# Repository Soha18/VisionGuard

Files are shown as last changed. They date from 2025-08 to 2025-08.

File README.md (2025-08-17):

# VisionGuard 👁️📺

An intelligent IoT child safety system that promotes healthy TV viewing habits by automatically monitoring viewing distance and controlling television access through advanced Time-of-Flight sensing technology.

## 🚀 Features

- **Multi-Zone Distance Monitoring**: VL53L5CX 8×8 zone ToF sensor with 64 independent detection areas
- **Intelligent TV Control**: Configurable IR transmission with LG TV optimization and multi-brand support
- **Dual-Threshold Hysteresis**: Prevents false triggers with smart grace period management
- **Grove Ecosystem Integration**: I2C expansion port supporting 300+ sensor modules (Rev 2)
- **ESPHome Framework**: Web interface with real-time configuration and OTA updates
- **WiFi 6 Ready**: ESP32-C6 with native USB-JTAG and Bluetooth 5.3 LE
- **Professional Grade**: Dual power input, ESD protection, and enhanced reliability

## 🛠️ Hardware Specifications

### Core Components
- **MCU**: ESP32-C6-MINI-1-N4 (RISC-V dual-core, 4MB flash)
- **Sensor**: VL53L5CX Time-of-Flight (50mm-4000mm range, 45°×45° FOV)
- **Power**: USB-C 5V with ST1L05APU33R 3.3V LDO (1.5A capacity)
- **IR**: 940nm LED with 100mA drive capability, 3m+ range
- **Expansion**: Grove I2C connector (Rev 2) with 5V/3.3V power delivery
- **Protection**: Comprehensive ESD, surge, and overcurrent protection

### Performance
- **Detection Range**: 0.3m - 4.0m with ±30mm accuracy
- **Response Time**: <300ms from detection to IR output
- **Update Rate**: 1-60Hz configurable, 5Hz default
- **Power Consumption**: 65-85mA normal, 180-200mA peak
- **Operating Temp**: -10°C to +60°C

## 🔧 Quick Start

### Hardware Setup
1. **Programming**: Connect USB-C cable for native JTAG programming
2. **Installation**: Mount device near TV with clear sensor view of seating area
3. **Power**: Use included USB-C cable or Grove power input (Rev 2)

### Firmware Development
For detailed firmware setup and development environment:
- **ESPHome Environment**: See [FIRMWARE/ESPHome/README.md](FIRMWARE/ESPHome/README.md)
- **Docker Setup**: Complete containerized development environment
- **Configuration Guide**: [FIRMWARE/ESPHome/User_Guide_Rev_1.md](FIRMWARE/ESPHome/User_Guide_Rev_1.md)

### End User Setup
For complete installation and usage instructions:
- **User Manual**: [docs/USER_MANUAL.md](DOCS/visionguard_user_manual.md)
- **Web Interface**: Access device IP after WiFi configuration
- **Troubleshooting**: Common issues and solutions included in user manual

## 🔬 Technical Overview

### Unique Architecture Features
- **STM API Integration**: Custom ESPHome component wrapping STMicroelectronics VL53L3CX/VL53L5CX drivers
- **Dual-Threshold Hysteresis**: Intelligent state management prevents false triggers
- **Multi-Target Processing**: Advanced histogram analysis and spatial filtering
- **Hardware Interrupt Integration**: Low-latency sensor response with ESPHome framework

### Development Stack
- **Framework**: ESPHome with ESP-IDF backend
- **Programming**: Native USB-JTAG via ESP32-C6
- **API**: Custom sensor components and IR protocol libraries
- **Power Management**: Intelligent dual-input switching (Rev 2)

**For complete technical specifications**: See [Technical Documentation](DOCS/technical_doc_rev2.md)

## 🏗️ Hardware Revisions

### Revision 1
- Single-zone VL53L3CX sensor
- USB-C power and programming
- Compact 1.5×5cm form factor
- Production ready design

### Revision 2
- Multi-zone VL53L5CX sensor (8×8 array)
- Grove I2C expansion connector
- Enhanced power management
- Extended environmental specifications

## 📊 Applications

- **Child Safety**: Primary use case for healthy viewing habits
- **Robotics**: Navigation and obstacle avoidance systems  
- **Industrial**: Safety curtains and access control
- **IoT/Smart Home**: Occupancy detection and automation
- **Security**: Spatial intrusion detection systems

### Getting Started
- **Development Environment**: [FIRMWARE/ESPHome/README.md](FIRMWARE/ESPHome/README.md)
- **Technical Architecture**: [docs/TECHNICAL.md](DOCS/technical_doc_rev2.md)
- **Hardware Design**: See [hardware/](hardware/) directory

## 📄 License

This project is licensed under the MIT License - see the [LICENSE](LICENSE) file for details.

---
**Version**: 2.0 | **Hardware**: Rev 1 Production, Rev 2 Development | **Status**: Active Development | **Updated**: August 2025

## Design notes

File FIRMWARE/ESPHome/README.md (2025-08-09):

# ESPHome Firmware Environment for VisionGuard

This directory contains the ESPHome firmware environment for the VisionGuard project. It provides a Docker-based setup for building, flashing, and managing ESPHome devices, including the VisionGuard Rev.1 hardware.

## Requirements

- **Docker**: Ensure Docker is installed on your system. [Install Docker](https://docs.docker.com/get-docker/)
- **Docker Compose**: Required to orchestrate the ESPHome container. [Install Docker Compose](https://docs.docker.com/compose/install/)
- **Supported OS**: Linux (recommended), macOS, or Windows with Docker support.
- **ESP32 Device**: The stack is configured for ESP32-C6-DevKitM-1 hardware.

## Directory Structure

- `docker-compose.yaml` — Docker Compose file to launch the ESPHome service.
- `config/` — Contains all ESPHome YAML configuration files, secrets, and custom components:
  - `vision-guard-rev-1.yml` — Main ESPHome config for VisionGuard Rev.1.
  - `secrets.yaml` — WiFi and sensitive credentials (not included in version control).
  - `my_components/` — Custom ESPHome components (e.g., VL53L3CX sensor driver).

## Getting Started

1. **Clone the Repository**

   ```bash
   git clone <this-repo-url>
   cd FIRMWARE/ESPHome
   ```

2. **Configure Secrets**

   - Copy `config/secrets.yaml.example` to `config/secrets.yaml` (if provided), and fill in your WiFi credentials and other secrets.

3. **Connect Your ESP32 Device**

   - Plug your ESP32 device into your computer. The container is pre-configured to access `/dev/ttyACM0` through `/dev/ttyACM6`.

4. **Start ESPHome**

   Launch the ESPHome dashboard using Docker Compose:

   ```bash
   docker compose up -d
   ```

   This will start the ESPHome web dashboard on port 6052 (default ESPHome port) or as configured.

5. **Access the ESPHome Dashboard**

   Open your browser and go to:

   ```
   http://localhost:6052
   ```
   (Or the port mapped by Docker, if different.)

6. **Build, Upload, and Monitor Firmware**

   - Use the ESPHome dashboard to build and upload firmware to your device.
   - The `config/vision-guard-rev-1.yml` file contains the main configuration for the VisionGuard Rev.1 device, including sensor, IR, and automation logic.

## Notes

- The container runs with `privileged: true` and `network_mode: host` to allow direct access to USB devices and network discovery.
- The `config/` folder is mounted into the container, so any changes to YAML files or custom components are immediately available in ESPHome.
- For advanced configuration, refer to the [ESPHome documentation](https://esphome.io/).

## Stopping the Stack

To stop the ESPHome service:

```bash
docker compose down
```

---

For more details on the VisionGuard firmware logic, see `config/vision-guard-rev-1.yml` and the technical documentation in the main project `DOCS/` folder.

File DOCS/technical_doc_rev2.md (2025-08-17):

# VisionGuard Technical Documentation - Revision 2

## 1. Project Overview

### 1.1 System Description
VisionGuard Revision 2 represents a significant evolution of the intelligent child safety monitoring platform, incorporating advanced multi-zone Time-of-Flight sensing technology and expandable I/O capabilities. The system maintains its core functionality of automatic television access control while adding enhanced detection precision and modular expansion capabilities for diverse applications.

### 1.2 Design Objectives
- **Enhanced Sensing Platform**: Integration of VL53L5CX multi-zone ToF sensor for superior spatial awareness
- **Modular Expansion**: Grove I2C connector enabling integration with external sensors and actuators
- **Robust Power Management**: Dual power input system with intelligent switching and protection
- **Advanced Framework Integration**: Continued development of STMicroelectronics API adaptation with ESPHome
- **Multi-Application Platform**: Optimized for child safety, robotics navigation, industrial automation, and IoT applications
- **Professional Grade**: Enhanced reliability and diagnostic capabilities for commercial deployment

### 1.3 Key Improvements over Revision 1
- **Sensor Upgrade**: VL53L3CX → VL53L5CX (single zone → 8×8 multi-zone detection)
- **Expandability**: Addition of Grove I2C connector for modular sensor integration
- **Power Management**: Intelligent dual-input power switching with surge protection
- **Enhanced Protection**: Comprehensive ESD and overcurrent protection circuits
- **Diagnostic Features**: Hardware status indicators and advanced fault detection

## 2. System Architecture

### 2.1 Core Components Evolution

**Main Control Unit (MCU)**: ESP32-C6-MINI-1-N4 (U1) - Unchanged
- **RISC-V Architecture**: Proven 32-bit dual-core processor
- **Integrated Connectivity**: Native WiFi 6 and Bluetooth 5.3 LE
- **JTAG Programming**: Native USB-JTAG interface with precision USB design
- **Memory**: 4MB embedded flash with expanded configuration storage requirements
- **GPIO Allocation**: Optimized pin assignment for enhanced I/O requirements

**Advanced Distance Sensing System**: VL53L5CXV0GC/1 (U3) - Major Upgrade
- **Multi-Zone Detection**: 8×8 zone array (64 independent measurements) vs. single zone
- **Enhanced Field of View**: 45° × 45° with spatial resolution capabilities
- **Measurement Range**: 50mm to 4000mm with per-zone accuracy
- **Advanced Features**: Gesture recognition, motion detection, multiple target tracking
- **STM API Integration**: Extended driver supporting full multi-zone capabilities
- **Interrupt System**: Hardware interrupt with zone-specific event generation
- **Power Efficiency**: Programmable zone activation for optimized power consumption

**Intelligent Power Architecture**: Dual-Input System
- **Primary Path**: USB-C with standard 5V delivery
- **Auxiliary Path**: Grove connector enabling system-level power integration
- **Automatic Switching**: TPS2121RUXR (U5) seamless transition between sources
- **Protection Stack**: MAX40200AUK+T (U6) + IP4220CZ6,125 (D5) comprehensive fault protection

**Modular Expansion Interface**: Grove I2C Ecosystem (CN1)
- **Standard Compliance**: Seeed Grove 4-pin connector with I2C protocol
- **Power Delivery**: 5V/1A + 3.3V/500mA for diverse sensor requirements
- **Signal Integrity**: Dedicated I2C bus with proper termination and ESD protection
- **Ecosystem Access**: 300+ Grove modules including sensors, actuators, displays, communication

### 2.2 Design Philosophy and Implementation Strategy

**Spatial Intelligence Implementation**:
The transition to multi-zone sensing required fundamental firmware architecture changes:
- **Memory Architecture**: Efficient handling of 64 simultaneous distance measurements
- **Processing Pipeline**: Real-time spatial analysis with sub-100ms response time
- **Algorithm Development**: Custom zone filtering, object classification, and gesture recognition
- **API Integration**: Extended STM VL53L5CX API adaptation maintaining ESPHome compatibility

**Modular Expansion Strategy**:
Grove integration enables transformation from fixed-function device to adaptable platform:
- **Hardware Abstraction**: Standardized I2C interface supporting diverse modules
- **Software Framework**: Dynamic device discovery and configuration management
- **Power Management**: Intelligent power budgeting for multiple concurrent modules
- **Ecosystem Leverage**: Access to established Grove sensor and actuator library

**Reliability Engineering**:
Enhanced protection and fault tolerance for professional applications:
- **Multi-Stage Protection**: ESD, overcurrent, and surge protection on all external interfaces
- **Fault Detection**: Real-time monitoring with diagnostic reporting capabilities
- **Graceful Degradation**: System maintains core functionality during component failures
- **Power Redundancy**: Automatic failover between power sources without interruption

### 2.3 Hardware Interface Specifications

**VL53L5CX Control Interface**:
- **I2C Address**: 0x29 (7-bit addressing)
- **Control Signals**: 
  - LPN (Low Power): GPIO-controlled power management
  - INT: Interrupt output for measurement completion
  - RST: Hardware reset capability
- **Supply Requirements**: 2.8V I/O, 1.8V analog (internally regulated)
- **Signal Processing**: On-chip histogram analysis and multi-target separation

**Grove Connector Pinout** (CN1):
```
Pin 1: VCC (5V, 1A max, fused)
Pin 2: GND (common ground)
Pin 3: I2C_SDA_EXT (3.3V logic, 2.2kΩ pull-up)
Pin 4: I2C_SCL_EXT (3.3V logic, 2.2kΩ pull-up)
```

**Power Input Specifications**:
- **USB-C**: 5V ±5%, 1.5A maximum with PD negotiation
- **Grove**: 5V ±10%, 1A maximum auxiliary input
- **Switching**: <10ms transition time between sources
- **Efficiency**: >90% power conversion efficiency

## 3. Firmware Architecture and Multi-Zone Integration

**Enhanced Software Framework**: ESPHome with expanded VL53L5CX integration
**Multi-Zone Processing**: Advanced spatial algorithms for 64-zone analysis
**Grove Module Support**: Dynamic I2C device discovery and configuration

### 3.1 VL53L5CX Multi-Zone Implementation

**Unique STM API Integration Enhancement**:
- **64-Zone Data Handling**: Real-time processing of 8×8 distance matrix
- **Spatial Algorithms**: Custom zone filtering and object recognition
- **Memory Optimization**: Efficient handling of multi-zone data structures
- **Interrupt Processing**: Zone-specific event handling and prioritization
- **Configuration Management**: Per-zone parameter adjustment capabilities

**Multi-Zone Configuration Parameters**:
```yaml
VL53L5CX Advanced Settings:
- Resolution Mode: 8×8 (64 zones) or 4×4 (16 zones) selectable
- Detection Range: 50mm to 4000mm per zone
- Update Rate: 1-60Hz with zone-dependent timing
- Target Order: Distance or signal strength prioritization
- Zone Filtering: Configurable ignore masks for specific areas
- Gesture Detection: Motion pattern recognition algorithms
```

### 3.2 Enhanced Control Logic

**Multi-Zone State Machine**:
1. **SPATIAL_MONITORING**: Continuous 64-zone distance measurement
2. **ZONE_ANALYSIS**: Object detection and classification per zone  
3. **GESTURE_RECOGNITION**: Movement pattern analysis
4. **MULTI_TARGET_TRACKING**: Simultaneous object tracking
5. **INTELLIGENT_ACTION**: Context-aware response execution

**Advanced Threshold Management**:
- **Zone-Specific Thresholds**: Individual distance limits per detection zone
- **Spatial Hysteresis**: 2D hysteresis preventing edge oscillations  
- **Gesture Triggers**: Hand wave detection for user interaction
- **Multi-Object Logic**: Handling multiple simultaneous detections
- **Adaptive Sensitivity**: Learning algorithms for environment adaptation

**Grove Module Integration**:
- **Device Auto-Discovery**: I2C scanning and device identification
- **Dynamic Configuration**: Runtime module parameter adjustment
- **Data Fusion**: Combining VL53L5CX data with external sensor inputs
- **Modular Actions**: Triggering external devices via Grove modules

### 3.3 IR Protocol and External Control

**Enhanced IR Protocol Support**:
- **Multi-Device Control**: Simultaneous control of multiple IR devices
- **Zone-Based Actions**: Different actions for different spatial zones
- **Grove IR Modules**: Support for external IR transmitters via Grove
- **Protocol Library**: Expanded support for TV, projector, and AV equipment

## 4. Hardware Design Specifications - Revision 2

### 4.1 Advanced Electrical Design

**Power Consumption Analysis** (Multi-Zone Operation):
| Operating Mode | Current (mA) | Power (mW) | Notes |
|---|---|---|---|
| 64-Zone Active Sensing | 95-120 | 315-400 | VL53L5CX active |
| 16-Zone Reduced Power | 70-85 | 230-280 | 4×4 mode |
| WiFi + Multi-Zone | 150-180 | 500-600 | Peak operation |
| Grove Module Active | +20-50 | +65-165 | Variable per module |
| Deep Sleep | 0.08-0.15 | 0.25-0.5 | Enhanced sleep mode |

**Power Distribution Design**:
- **5V Rail**: Dual-input with TPS2121 automatic switching
- **3.3V Main**: ST1L05APU33R providing 1.5A capability
- **Current Budget**: MCU (80mA) + VL53L5CX (40mA) + Grove (50mA) = 170mA typical
- **Surge Protection**: MAX40200 provides 4A peak current limiting
- **ESD Protection**: IP4220CZ6,125 on all external interfaces

**Signal Integrity Enhancements**:
- **Multi-Zone Data**: High-speed I2C with 64-zone data bandwidth
- **USB Differential Pairs**: Maintained 90Ω ±10% impedance
- **Grove I2C**: Dedicated 33Ω series termination for signal integrity
- **Power Distribution**: Enhanced decoupling with zone-specific filtering
- **Ground Plane**: Improved ground distribution for multi-zone sensor

### 4.2 PCB Layout Evolution

**Enhanced Form Factor Considerations**:
- **Sensor Positioning**: VL53L5CX optimally placed for maximum FOV
- **Grove Connector**: Side-mounted for easy external module connection
- **USB-C Orientation**: Maintained back-side positioning for clean installation
- **Component Density**: Increased component count with optimized placement
- **Thermal Management**: Enhanced thermal design for higher power operation

### 4.3 Bill of Materials - Revision 2 Critical Components

| Designator | Component | Part Number | Function | Rev1 Comparison |
|---|---|---|---|---|
| U1 | ESP32-C6 | ESP32-C6-MINI-1-N4 | Main MCU | Unchanged |
| U3 | Multi-Zone ToF | VL53L5CXV0GC/1 | 64-zone distance sensing | Major upgrade from VL53L3CX |
| U2 | LDO Regulator | ST1L05APU33R | 3.3V regulation | Unchanged |
| U5 | Power Switch | TPS2121RUXR | Dual-input switching | New addition |
| U6 | Current Limiter | MAX40200AUK+T | Overcurrent protection | New addition |
| D5 | ESD Protector | IP4220CZ6,125 | USB/Grove protection | New addition |
| CN1 | Grove Connector | ZX-HY2.0-4PZZ | I2C expansion | New addition |
| Q1 | NPN Transistor | SS8050 | IR LED driver | Unchanged |
| LED1 | IR Emitter | DY-IRS302320C/6.5T | IR transmission | Unchanged |

## 5. Performance Specifications - Revision 2

### 5.1 Multi-Zone Detection Performance
| Parameter | Specification | Improvement over Rev1 |
|---|---|---|
| Detection Zones | 64 (8×8) or 16 (4×4) | +6300% spatial resolution |
| Zone Resolution | 5.6° per zone | Individual zone targeting |
| Simultaneous Targets | Up to 64 | Multiple object tracking |
| Gesture Recognition | Hand/body gestures | New capability |
| Update Rate | 1-60Hz per zone | Maintained with 64× data |
| Spatial Accuracy | ±30mm per zone | Maintained across all zones |

### 5.2 Grove Integration Performance
| Parameter | Specification |
|---|---|
| I2C Bus Speed | Up to 400kHz |
| Module Discovery | <1s auto-detection |
| Concurrent Modules | Up to 8 devices |
| Power Delivery | 5V @ 1A, 3.3V @ 500mA |
| Cable Length | Up to 2m Grove cable |

### 5.3 Enhanced Environmental Specifications
| Parameter | Minimum | Maximum | Unit | Notes |
|---|---|---|---|---|
| Operating Temperature | -20 | +70 | °C | Extended range |
| Multi-Zone Operation | -10 | +60 | °C | Full 64-zone capability |
| Humidity | 5 | 95 | % RH | Non-condensing |
| Vibration Resistance | - | 10G | - | Enhanced for mobile robotics |

## 6. Applications and Use Cases - Revision 2

### 6.1 Enhanced Child Safety Applications
- **Multi-Child Detection**: Simultaneous monitoring of multiple children
- **Spatial Awareness**: Zone-specific safety enforcement  
- **Gesture Control**: Hand wave commands for interaction
- **Parent Override**: Gesture-based temporary disable

### 6.2 Robotics and Automation
- **Navigation**: 64-zone obstacle detection for mobile robots
- **Localization**: Spatial landmark detection and mapping
- **Human-Robot Interaction**: Gesture-based robot control
- **Industrial Automation**: Multi-zone safety curtains and access control

### 6.3 IoT and Smart Home Integration
- **Occupancy Detection**: Room-level presence sensing with zone resolution
- **Activity Recognition**: Movement pattern analysis for smart lighting
- **Security Systems**: Intrusion detection with spatial discrimination
- **Energy Management**: Zone-based HVAC control optimization

### 6.4 Grove Ecosystem Integration
- **Environmental Monitoring**: Temperature, humidity, air quality sensors
- **Display Systems**: OLED/LCD status displays via Grove
- **Wireless Communication**: LoRa, Zigbee modules for extended connectivity
- **Actuator Control**: Servo motors, relays, and output devices

## 7. Manufacturing and Quality - Revision 2

### 7.1 Advanced Assembly Requirements
- **Multi-Zone Calibration**: Factory calibration of 64-zone sensor array
- **Grove Interface Testing**: Automated testing of I2C expansion capability
- **Dual Power Testing**: Verification of automatic power switching functionality
- **Spatial Alignment**: Precise sensor mounting for optimal FOV coverage

### 7.2 Enhanced Quality Assurance
- **Multi-Zone Verification**: Per-zone distance accuracy testing
- **Grove Compatibility**: Testing with standard Grove sensor modules
- **Power Management**: Dual-input switching and protection verification
- **Long-term Reliability**: Extended burn-in testing for commercial applications

---

*Document Version: 2.0*  
*Hardware Revision: 2*  
*Supersedes: VisionGuard Revision 1 Technical Documentation*  
*Last Updated: August 2025*  
*Classification: Advanced Technical Design Specification*

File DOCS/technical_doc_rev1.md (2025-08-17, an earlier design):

# VisionGuard Technical Documentation - Revision 1

## 1. Project Overview

### 1.1 System Description
VisionGuard is an intelligent child safety monitoring system designed to automatically control television access based on viewing distance. The device employs Time-of-Flight (ToF) sensing technology to continuously monitor viewer proximity and executes predefined actions via infrared transmission when unsafe viewing distances are detected.

### 1.2 Design Objectives
- **Primary Function**: Proof of concept for integrating VL53L3CX ToF sensor with ESP32-C6 architecture and implementation of STMicroelectronics API adaptation with ESPHome/ESP-IDF framework
- **Child Safety Application**: Automatic enforcement of safe TV viewing distances as primary use case
- **Versatile Platform**: Expandable architecture for robotics applications (exploration robots, localization systems), gate control systems, and industrial proximity monitoring
- **Smart Integration**: WiFi connectivity and web interface for IoT applications
- **Configurable Response**: User-defined thresholds and behavioral actions

## 2. System Architecture

### 2.1 Core Components Selection Strategy

**Main Control Unit (MCU)**: ESP32-C6-MINI-1-N4 (U2)
- **RISC-V Architecture**: Modern 32-bit processor with dual-core capability
- **Integrated Connectivity**: Native WiFi 6 (802.11ax) and Bluetooth 5.3 LE
- **JTAG Programming**: Native USB-JTAG interface requiring precise USB differential pair design
- **Memory**: 4MB embedded flash for application code and configuration storage

**Distance Sensing System**: VL53L3CXV0DH/1 (U1) - STMicroelectronics Time-of-Flight Sensor
- **Measurement Range**: 50mm to 4000mm operational range covers typical applications
- **Accuracy**: ±3% precision at 1-2m distances (optimal for most use cases)
- **I2C Interface**: Standard communication protocol with configurable address (0x29)
- **STM API Adaptation**: Custom driver integration with ESPHome framework - unique implementation
- **Interrupt Capability**: Hardware interrupt on measurement completion reduces polling overhead

**Power Management Architecture**: ST1L05APU33R (U3) Low-Dropout Regulator
- **Input Range**: 5V USB-C input with comprehensive surge protection
- **Output**: Stable 3.3V supply rated at 1.5A maximum current
- **Voltage Drop Calculation**: 200mV typical dropout ensures 3.1V minimum at 300mA load
- **Current Budget**: MCU (80mA) + Sensor (20mA) + IR LED (100mA peak) = 200mA minimum
- **Thermal Protection**: Integrated over-temperature shutdown with thermal pad
- **Package**: SOT-323 surface mount optimized for 1.5×5cm PCB constraint

**Infrared Transmission System**: DY-IRS302320C/6.5T (U5) with SS8050 Driver (Q1)
- **Wavelength**: 940nm optimized for consumer electronics IR receivers
- **Drive Current Calculation**: 100mA peak through 220Ω base resistor with β=200 transistor gain
- **Power Dissipation**: 330mW peak (100mA × 3.3V) during transmission bursts
- **Protocol Flexibility**: Configurable IR protocols with LG TV as default tested implementation
- **Range**: >3m transmission distance for typical applications

### 2.2 Critical Design Considerations

**USB-C Interface Design**: TYPE-C 16PLT-H10.0 (U4)
The ESP32-C6 uses native USB-JTAG (not UART bridge) requiring precise differential pair design:
- **Impedance Control**: 90Ω ±10% differential impedance maintained across PCB traces
- **Trace Length**: D+/D- matched within ±0.1mm, total length <50mm for signal integrity
- **Capacitive Loading**: 4.7µF bulk capacitors positioned <5mm from connector
- **CC Resistors**: 5.1kΩ precision resistors for USB-C power negotiation
- **Current Limiting**: MF-MSMF110/16-2 resettable fuse rated for inrush protection

**PCB Layout Architecture**: 1.5×5cm Form Factor
- **Orientation Strategy**: USB-C connector on back side, sensor and IR LED on front side
- **Installation Advantage**: Front-facing sensors allow direct TV screen mounting
- **Component Density**: High-density layout with 0402 passive components
- **Ground Plane**: Continuous ground pour with strategic via stitching
- **Power Distribution**: Star topology from LDO to minimize voltage drops
- **Bulk Capacitance**: 22µF tantalum + 4.7µF ceramic near USB connector for inrush current limiting
- **Thermal Management**: Thermal vias under power components for heat dissipation

**I2C Bus Implementation**:
- **Clock Frequency**: 38kHz optimized for VL53L3CX sensor timing requirements
- **Pull-up Resistors**: 2.2kΩ (R4, R5) calculated for 3.3V logic with 400pF bus capacitance
- **GPIO Assignment**: SDA=GPIO6, SCL=GPIO7 with internal weak pull-ups disabled
- **Signal Integrity**: <10pF parasitic capacitance maintained through careful routing

## 3. Firmware Architecture and STM API Integration

**Software Framework**: ESPHome with ESP-IDF backend and custom STM API adaptation
**Real-Time OS**: FreeRTOS kernel for task scheduling
**Development Framework**: YAML configuration with C++ lambda extensions

### 3.1 Unique STM API Adaptation
This project features a novel integration of STMicroelectronics VL53L3CX API with the ESPHome framework:
- **Custom Component**: Native ESPHome component wrapping STM's official API
- **Memory Management**: Adaptation of STM's dynamic allocation to ESP-IDF heap management
- **Interrupt Handling**: Integration of STM interrupt callbacks with ESPHome's GPIO system
- **Configuration Bridge**: YAML parameter mapping to STM's configuration structures
- **Multi-Target Support**: Full exposure of STM's advanced ranging capabilities

### 3.2 Sensor Management System

**VL53L3CX Driver Configuration**:
- Distance Mode: MEDIUM (up to 2.90m range)
- Timing Budget: 80ms (accuracy vs. speed balance)
- Update Interval: 200ms (system responsiveness)
- Signal Processing: Exponential moving average (α=0.1)

**Multi-Target Processing Algorithm**: Custom histogram analysis with STM API integration
- Merge Threshold: 12000 units (target separation)
- Noise Threshold: 50 units (weak signal rejection)
- Signal Rate Limit: 0.1 MCPS (minimum acceptable return)
- Sigma Threshold: 60mm (measurement uncertainty limit)

### 3.3 Control Logic Implementation

**State Machine Architecture**:
1. MONITORING: Continuous distance measurement
2. GRACE_PERIOD: Countdown before action execution  
3. ACTION_ACTIVE: IR command transmission
4. RECOVERY_HOLD: Waiting for distance recovery

**Dual-Threshold Hysteresis System**:
- Close Threshold: 0.8m default (user configurable 0.3-2.0m)
- Far Threshold: 1.0m default (user configurable 0.5-3.0m)
- Dead Band: Prevents oscillation between states
- Grace Period: 2s default delay before action execution

**Action Execution Framework**:
- Near Actions (child too close): Mute, Power Off, Input switching, Navigation commands
- Far Actions (child moved away): Unmute, Power On, Input restoration
- IR repeat count: 3 transmissions with 50ms intervals
- Command verification through state tracking

### 3.4 IR Protocol Implementation

**Configurable Protocol Support**: The system supports multiple IR protocols with LG TV as the default tested configuration:
- **Primary Protocol**: NEC encoding with LG address prefix (0x20DF)
- **Alternative Protocols**: Samsung, Sony, Panasonic (configurable via firmware)
- **Carrier Frequency**: 38kHz with 50% duty cycle
- **Bit Encoding**: PWM with protocol-specific timing requirements

**LG TV Command Set (Default Configuration)**:
```
Verified Commands:
- Power: 0x20DF10EF
- Mute: 0x20DF906F  
- Input: 0x20DFD02F
- HDMI1: 0x20DF738C
- HDMI2: 0x20DF33CC
- HDMI3: 0x20DF9768
```

**Transmission Strategy**:
- Multiple transmission repeats (user configurable 1-5)
- Inter-command delays (50ms) prevent receiver overflow
- Queue management for sequential commands
- Error recovery through state machine reset

## 4. Hardware Design Specifications

### 4.1 Electrical Design and Power Analysis

**Power Consumption Analysis**:
| Operating Mode | Current (mA) | Power (mW) | Duration |
|---|---|---|---|
| Active Sensing | 65-85 | 215-280 | Continuous |
| WiFi Transmission | 120-150 | 400-500 | Burst |
| IR Transmission | 180-200 | 600-660 | 100ms |
| Deep Sleep | 0.05-0.1 | 0.15-0.3 | Standby |

**LDO Design Calculations**:
- Input Voltage: 5.0V (USB-C nominal)
- Output Voltage: 3.3V regulated
- Maximum Load Current: 200mA (continuous), 300mA (peak)
- Voltage Drop: 1.7V (5.0V - 3.3V)
- Power Dissipation: 340mW @ 200mA load
- Thermal Resistance: 120°C/W (SOT-323 package)
- Temperature Rise: 41°C above ambient (acceptable for ≤45°C ambient)

**Signal Integrity Requirements**:
- I2C Bus: ±5% tolerance, <10pF parasitic capacitance
- USB Differential Pairs: 90Ω ±10% impedance, ±0.1mm length matching
- IR Drive Circuit: Fast rise/fall times (<1µs) for 38kHz modulation
- Power Rails: <50mV ripple at full load with bulk capacitor filtering

### 4.3 Bill of Materials - Critical Components

| Designator | Component | Part Number | Function | Selection Criteria |
|---|---|---|---|---|
| U2 | ESP32-C6 | ESP32-C6-MINI-1-N4 | Main MCU | RISC-V architecture, native USB-JTAG, WiFi 6 |
| U1 | ToF Sensor | VL53L3CXV0DH/1 | Distance measurement | 4m range, I2C interface, STM API support |
| U3 | LDO Regulator | ST1L05APU33R | 3.3V regulation | 1.5A rating, low dropout, thermal protection |
| U5 | IR LED | DY-IRS302320C/6.5T | IR transmission | 940nm wavelength, 100mA drive capability |
| Q1 | NPN Transistor | SS8050 | IR LED driver | β=200 gain, fast switching, 100mA collector |
| U4 | USB-C Connector | TYPE-C 16PLT-H10.0 | Power/JTAG interface | USB-C standard, robust mounting |

## 5. Programming and Development Interface

**Firmware Flashing Procedure**:
- **Interface**: USB-C connector with native ESP32-C6 USB-JTAG support
- **Protocol**: JTAG debugging protocol (not UART bridge)
- **Tools**: ESPHome command line, ESP-IDF, or OpenOCD
- **Flash Process**: Direct JTAG programming via USB-C connection
  1. Connect USB-C cable to development host
  2. Auto-detection via USB-JTAG bridge
  3. Execute: `esphome run vision-guard-rev-1.yml`
  4. Monitor via serial console or JTAG debugger

## 6. Performance Specifications

### 6.1 Detection Performance
| Parameter | Specification | Test Condition |
|---|---|---|
| Detection Range | 0.3m - 4.0m | Standard reflective target |
| Accuracy | ±30mm | At 1m distance |
| Response Time | <300ms | From detection to IR output |
| False Positive Rate | <1% | 8-hour continuous operation |
| Update Rate | 5 Hz | Configurable 1-60 Hz |

### 6.2 Environmental Specifications
| Parameter | Minimum | Maximum | Unit |
|---|---|---|---|
| Operating Temperature | -10 | +60 | °C |
| Storage Temperature | -40 | +85 | °C |
| Relative Humidity | 10 | 90 | % RH |
| Altitude | 0 | 3000 | meters |

### 6.3 Network Performance
| Parameter | Specification |
|---|---|
| WiFi Standards | 802.11 b/g/n/ax (2.4GHz) |
| Security | WPA3-Personal, WPA2-Personal |
| Range | 30m typical indoor |
| Connection Time | <10s from power-on |
| OTA Update Size | <2MB typical |

## 7. Safety and Compliance

### 7.1 Electrical Safety
- **Input Protection**: TVS diode for surge protection
- **Current Limiting**: Resettable fuse prevents overcurrent
- **Isolation**: No galvanic connection between USB and IR circuits
- **EMC**: Design practices for FCC Part 15 Class B compliance

### 7.2 IR Safety
- **Eye Safety**: IR LED power limited to IEC 62471 Class 1
- **Exposure Duration**: Pulse-based transmission minimizes continuous exposure
- **Wavelength**: 940nm outside visible spectrum

---

*Document Version: 1.0*  
*Hardware Revision: 1*  
*Firmware Version: ESPHome compatible*  
*Last Updated: August 2025*  
*Classification: Technical Design Specification*

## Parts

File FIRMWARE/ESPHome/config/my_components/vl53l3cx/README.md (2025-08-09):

# VL53L3CX ESPHome Component

ESPHome component for the ST VL53L3CX Time-of-Flight sensor with multi-target support.

## Features
- I2C communication interface using ESPHome's I2C abstraction
- Multi-target detection (up to 4 targets simultaneously)
- Configurable distance modes (SHORT, MEDIUM, LONG)
- Configurable timing budget (20ms to 1000ms)
- GPIO control for XSHUT and interrupt pins
- Binary sensor for data ready status
- Sensor hub architecture with individual sensors per target
- Critical sensor operation compliance (crosstalk compensation, range validation, etc.)

## Configuration (comprehensive example)

```yaml
esphome:
  name: vl53l3cx-demo

esp32:
  board: esp32-c6-devkitm-1
  framework:
    type: esp-idf

logger:
  level: DEBUG

i2c:
  - id: bus_a
    sda: GPIO6
    scl: GPIO7
    scan: true
    frequency: 100kHz

external_components:
  - source:
      type: local
      path: components
    components: [vl53l3cx]

vl53l3cx:
  - id: tof_sensor
    address: 0x29
    distance_mode: MEDIUM      # SHORT | MEDIUM | LONG
    timing_budget: 33ms        # 20..1000ms
    inter_measurement_period: 40ms  # >= timing_budget
    update_interval: 100ms          # >= inter_measurement_period

    # Optional accuracy/SNR tuning
    signal_rate_limit: 0.1     # MCPS
    sigma_threshold: 60.0      # mm

    # Multi-target tuning (advanced)
    target_order: DISTANCE     # or SIGNAL_STRENGTH
    # merge_threshold: 12000   # lower reduces pulse merging
    # hist_noise_threshold: 30 # lower to keep secondary peaks
    # hist_merge: true         # default
    # hist_merge_max_size: 8   # advanced

    # Optional ROI to narrow the field of view
    # roi:
    #   top_left_x: 6
    #   top_left_y: 14
    #   bottom_right_x: 9
    #   bottom_right_y: 5

    xshut_pin:
      number: GPIO3
      mode: { output: true, pullup: true }
    interrupt_pin:
      number: GPIO2
      mode: { input: true, pullup: false }

sensor:
  - platform: vl53l3cx
    vl53l3cx_id: tof_sensor
    name: "ToF Target 0 Distance"
    target_number: 0
  - platform: vl53l3cx
    vl53l3cx_id: tof_sensor
    name: "ToF Target 1 Distance"
    target_number: 1
  - platform: vl53l3cx
    vl53l3cx_id: tof_sensor
    name: "ToF Target 2 Distance"
    target_number: 2
  - platform: vl53l3cx
    vl53l3cx_id: tof_sensor
    name: "ToF Target 3 Distance"
    target_number: 3

binary_sensor:
  - platform: vl53l3cx
    vl53l3cx_id: tof_sensor
    name: "ToF Data Ready"
```

## Configuration Options (with defaults)

### Main Component (`vl53l3cx`)
- **distance_mode** (Optional, default: `MEDIUM`): Distance measurement mode
  - `SHORT`: Up to 1.36m, better ambient immunity
  - `MEDIUM`: Up to 2.90m (default), maximum distance
  - `LONG`: Up to 3.60m, lower power consumption
- **timing_budget** (Optional, default: `33ms`): Measurement timing budget, 20ms to 1000ms
- **inter_measurement_period** (Optional): Time between measurement starts (ms). Must be >= timing_budget. If omitted the component now applies a deterministic default of `timing_budget + 5ms` to avoid overlap while maximizing throughput.
- **update_interval** (Optional, default: `100ms`): How often to poll for new data (must be >= inter_measurement_period). The sensor free-runs internally; polling only fetches ready results.
- **xshut_pin** (Optional): GPIO pin for XSHUT control (hardware reset)
- **interrupt_pin** (Optional): GPIO pin for interrupt input (data ready signal)
- **address** (Optional): I2C address (default: 0x29)
- **merge_threshold** (Optional, default: `15000`): Multi-target separation threshold. Lower (e.g. 12000) separates nearby targets more aggressively. Applied deterministically even if not set.
- **hist_noise_threshold** (Optional, default: `50`): Histogram noise floor. Lower (e.g. 30) preserves weaker secondary peaks at cost of more noise.
- **hist_merge** (Optional, default: `true`): Enable histogram merge algorithm. Disable only for debugging or very specialized scenes.
- **hist_merge_max_size** (Optional, default: `8`): Limit on histogram merge window size (1..16). Larger allows broader pulse grouping.
- **signal_rate_limit** (Optional, default: `0.1` MCPS): Minimum return rate; lower is more permissive.
- **sigma_threshold** (Optional, default: `60.0` mm): Maximum allowed sigma (measurement uncertainty). Higher tolerates noisier data.
- **smudge_correction_mode** (Optional, default: `CONTINUOUS`): One of `DISABLE`, `CONTINUOUS`, `SINGLE`, `DEBUG`. (`DISABLE` maps to vendor `NONE`).
- **target_order** (Optional, default: `DISTANCE`): Sort multi-target results by distance or signal strength.
- **roi** (Optional): Restrict field-of-view. Coordinates validated so that `top_left_x <= bottom_right_x` and `top_left_y <= bottom_right_y` in the SPAD array (0..15 each axis).

Note: Multi-target detection is always enabled (up to 4 targets). Use merge_threshold and histogram tuning to adjust separation aggressiveness.

### Sensor Platform
- **vl53l3cx_id** (Required): Reference to the main component
- **target_number** (Optional): Target index for multi-target mode (0-3, default: 0)
- All standard ESPHome sensor options (name, filters, etc.)

### Binary Sensor Platform
- **vl53l3cx_id** (Required): Reference to the main component
- All standard ESPHome binary sensor options (name, filters, etc.)

## Key Features

### Critical Sensor Operation Compliance & Deterministic Defaults
- **Crosstalk Compensation**: Forced enabled at startup (ST library leaves it disabled by default)
- **Smudge Correction**: Multi-mode; default CONTINUOUS. Modes: DISABLE (off), CONTINUOUS (recommended), SINGLE (one-shot), DEBUG (diagnostic without auto updates).
- **Offset Correction**: Per-VCSEL mode after calibration for optimal accuracy
- **Deterministic Advanced Defaults**: merge_threshold=15000, hist_noise_threshold=50, hist_merge=true, hist_merge_max_size=8 always applied for consistent behavior across firmware versions
- **Range1 Discard**: First measurement discarded per ST guidance
- **StreamCount Rollover Handling**: Detects missed measurements
- **Robust Error Recovery**: Context-specific retry/backoff strategies
- **I2C Chunking**: Large transactions split into 32-byte segments

### ESPHome Integration
- **PollingComponent**: Proper ESPHome polling component with configurable update intervals
- **Sensor Hub Architecture**: Up to 4 individual distance sensors per device
- **I2C Abstraction**: Full integration with ESPHome's I2C system including transaction chunking
- **GPIO Control**: Optional XSHUT (reset) and interrupt pin support
- **Binary Sensor**: Data ready status indication

## Technical Architecture

The component consists of:
- **Main Hub Component** (`vl53l3cx.cpp/h`): PollingComponent that manages sensor hardware and implements critical ST VL53L3CX operations
- **Distance Sensor Platform** (`sensor/`): Individual ESPHome sensors for each of the 4 possible targets
- **Binary Sensor Platform** (`binary_sensor/`): Data ready status indicator
- **ST Core Drivers** (`vl53lx_*.c/h`): ST's VL53LX driver library integrated with full functionality
- **ESPHome Platform Bridge** (`vl53lx_platform.cpp`): Custom I2C implementation with chunking support for large transactions

### Integration Strategy
- **Core Driver Integration**: Uses ST's complete VL53LX driver for device control
- **Platform Abstraction Replacement**: Custom ESPHome-compatible platform layer
- **I2C Transaction Chunking**: Handles large register writes (up to 135 bytes) via 32-byte chunks
  and large reads using the same chunking strategy
- **Memory Management**: Dynamic allocation for 9432-byte device structure

## Hardware Requirements

- **ESP32** with ESP-IDF framework (Arduino framework not supported)
- **I2C Bus**: 400 kHz recommended, pull-up resistors required
- **Power**: 2.6V to 3.5V supply
- **Optional GPIO**: XSHUT (reset) and GPIO1 (interrupt) pins

## Software Requirements

- **ESPHome**: 2023.8.0 or newer
- **Framework**: ESP-IDF only (Arduino framework not compatible)
- **I2C Component**: Must be configured in ESPHome

## Important Notes

### Factory Calibration Required
For optimal accuracy, the sensor requires factory calibration:
1. **RefSPAD Calibration**: No target required
2. **Crosstalk Calibration**: Target at 600mm in dark environment
3. **Offset Calibration**: Known target distance, signal rate 2-80 MCps

#### Calibration buttons (ESPHome/HA)
- RefSPAD: "ToF RefSPAD Calibration" (ensure clear path; no target)
- Crosstalk: "ToF Crosstalk Calibration (600mm)" (17% target at exactly 600 mm, dark)
- Offset: "ToF Offset Calibration" (known distance; component uses Per-VCSEL mode)
- Zero-distance (field): "ToF Zero-Distance Calibration" (target touching cover glass)

Flow: Run in the above order. The component stops ranging, performs calibration via ST APIs, re-enables crosstalk compensation when needed, then restarts ranging. Persistence of calibration data is planned.
 
#### Persistence
- Calibration data is saved automatically to ESPHome preferences after each calibration step and reloaded on boot.
- Data is keyed by I2C address, so multiple sensors on the same node are supported.
- To clear stored calibration, use ESPHome’s preferences reset or change the I2C address.

### Multi-Target Detection
- Always enabled, can detect up to 4 targets simultaneously
- Targets are automatically sorted by distance (closest first)
- Each target gets its own sensor entity in ESPHome
- "No target" condition reports 8.191m distance

### Performance Characteristics
- **Update Rate**: Configurable via `update_interval` (default 100ms)
- **Timing Budget**: 20ms to 1000ms affects accuracy vs. speed
- **Distance Modes**: SHORT/MEDIUM/LONG affect range vs. ambient immunity
- **Memory Usage**: 9432 bytes allocated for device structure

## License

This component incorporates ST's VL53LX driver library under ST's license terms.

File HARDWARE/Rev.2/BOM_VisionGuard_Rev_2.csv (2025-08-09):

No. | Quantity | Comment | Designator | Footprint | Value | Manufacturer Part | Manufacturer | Supplier Part | Supplier | Device | Description
1 | 8 | 100nF | C1,C4,C7,C10,C12,C15,C16,C18 | C0402 | 100nF | CL05B104KA5NNNC | SAMSUNG(三星) | C155422 | LCSC | CL05B104KA5NNNC | Capacitance: Tolerance:±10% Tolerance:±10% Voltage Rated: Temperature Coefficient:,Capacitance: Tolerance:±10% Tolerance:±10% Voltage Rated: Temperature Coefficient:
2 | 1 | 47uF | C2 | CAP-SMD_L6.0-W3.2-R-RD | 47uF | 293D476X9016C2TE3 | VISHAY(威世) | C129697 | LCSC | 293D476X9016C2TE3 | Capacitance: Tolerance:±10% Tolerance:±10% Rated Voltage: Equivalent Series Resistance(ESR):1Ω@100kHz Operating Temperature:-55℃~+125℃ Operating Temperature:-55℃~+125℃
3 | 4 | 10uF | C3,C6,C17,C19 | C0805 | 10uF | CL21B106KPQNNNE | SAMSUNG(三星) | C32635 | LCSC | CL21B106KPQNNNE | Capacitance: Tolerance:±10% Tolerance:±10% Voltage Rated: Temperature Coefficient:
4 | 1 | 22uF | C5 | CASE-A_3216 | 22uF | TAJA226K010RNJ | Kyocera AVX | C11366 | LCSC | TAJA226K010RNJ | Capacitance:22uF Tolerance:±10% Tolerance:±10% Voltage Rating:10V Equivalent Series Resistance(ESR):3Ω@100kHz Operating Temperature:-55℃~+125℃ Operating Temperature:-55℃~+125℃
5 | 1 | 1nF | C8 | C0402 | 1nF | CC0402KRX7R8BB102 | YAGEO(国巨) | C541372 | LCSC | CC0402KRX7R8BB102 | Capacitance: Tolerance:±10% Tolerance:±10% Voltage Rated: Temperature Coefficient:
6 | 2 | 4.7uF | C9,C13 | C0603 | 4.7uF | CL10A475KP8NNNC | SAMSUNG(三星) | C1705 | LCSC | CL10A475KP8NNNC | Capacitance: Tolerance:±10% Tolerance:±10% Voltage Rated: Temperature Coefficient:
7 | 3 | 1uF | C11,C14,C20 | C0603 | 1uF | CL10A105KO8NNNC | SAMSUNG(三星) | C1592 | LCSC | CL10A105KO8NNNC | Capacitance: Tolerance:±10% Tolerance:±10% Voltage Rated: Temperature Coefficient:
8 | 1 | ZX-HY2.0-4PZZ | CN1 | CONN-TH_4P-P2.00_HX20020-4A_2 |  | ZX-HY2.0-4PZZ | Megastar(兆星) | C7429580 | LCSC | ZX-HY2.0-4PZZ | Pins Structure:1x4P Pitch:2mm Mounting Type:Through Hole Reference Series:HY Number of Pins:4P Number of Rows:1 Number of PINs Per Row:4 Row Spacing:- Current Rating:2A Contact Material:Brass Contact Plating:Tin Operating Temperature:-25℃~+85℃ Operating T
9 | 2 | BAT54SW,115 | D1,D2 | SOT-323_L2.0-W1.3-P1.30-LS2.1-BR |  | BAT54SW,115 | Nexperia(安世) | C78606 | LCSC | BAT54SW,115 | Diode Configuration:1对串联式 Forward Voltage (Vf@If):800mV@100mA Reverse Voltage (Vr):30V Average Rectified Current (Io):200mA Reverse Leakage Current (Ir):2uA@25V
10 | 2 | ESD9B5.0ST5G | D3,D4 | SOD-923_L0.8-W0.6-LS1.0-BI |  | ESD9B5.0ST5G | onsemi(安森美) | C111566 | LCSC | ESD9B5.0ST5G | polarity:Bi-Directional Reverse Stand-Off Voltage (Vrwm):5V Maximum Clamping Voltage:- Peak Pulse Power Dissipation (Ppp)@10/1000us:- Breakdown Voltage:5.8V Number of Lines:单路 Operating Temperature:-55℃~+150℃@(Tj) Operating Temperature:-55℃~+150℃@(Tj) Typ
11 | 1 | IP4220CZ6,125 | D5 | TSOP-6_L3.0-W1.5-P0.95-LS2.8-BR |  | IP4220CZ6,125 | Nexperia(安世) | C282546 | LCSC | IP4220CZ6,125 | Reverse Stand-Off Voltage (Vrwm):5.5V Voltage - Breakdown:6V Reverse Leakage Current (Ir):100nA Operating Temperature:-40℃~+85℃@(Ta) Operating Temperature:-40℃~+85℃@(Ta) level of protection:IEC 61000-4-2 Type:ESD Junction Capacitance:1pF
12 | 2 | nSMD150-16V | F1,F2 | F1206 |  | nSMD150-16V | 台湾陆海 | C2937115 | LCSC | nSMD150-16V | Voltage - Max:16V Current - Max:100A Hold Current:1.5A Trip Current:3A Power Dissipation:800mW Resistance - Initial (Ri) (Min):30mΩ Resistance - Post Trip (R1) (Max):130mΩ Time to Trip(Max):300ms Operating Temperature:-40℃~+85℃ Operating Temperature:-40℃~
13 | 1 | DY-IRS302320C/6.5T | LED1 | LED-SMD_L3.0-W2.0-R-RD |  | DY-IRS302320C/6.5T | TONYU(东裕) | C5438894 | LCSC | DY-IRS302320C/6.5T | Vf - Forward Voltage:1.3V~2V Vf - Forward Voltage:1.3V~2V Power Dissipation:150mW Wavelength:940nm Wavelength:940nm Radiant Intensity:150mW/sr Current - DC Forward (If):100mA Reverse Voltage:5V View Angle:35° Operating Temperature:-25℃~+80℃ Operating Temp
14 | 1 | SZYY0402B | LED2 | LED0402-RD_BLUE |  | SZYY0402B | yongyu(永裕光电) | C434447 | LCSC | SZYY0402B | Emitted Color:Blue Power Dissipation:- Forward Current:5mA Dominant Wavelength:466nm~469nm Dominant Wavelength:466nm~469nm Peak Wavelength:- Color Temperature:- Color Temperature:- Viewing Angle:120° Mounting Sytle:- Operating Temperature:-40℃~+85℃ Operat
15 | 1 | SS8050(RANGE:200-350) | Q1 | SOT-23-3_L2.9-W1.3-P1.90-LS2.4-BR |  | SS8050(RANGE:200-350) | CJ(江苏长电/长晶) | C2150 | LCSC | SS8050(RANGE:200-350)_C2150 | Transistor Type: Collector Current (Ic): Collector-Emitter Breakdown Voltage (Vceo): Power Dissipation (Pd): DC Current Gain (hFE@Ic,Vce):200@800mA,1V DC Current Gain (hFE@Ic,Vce):200@800mA,1V Transition Frequency (fT):100MHz Collector Cut-Off Current (Ic
16 | 4 | 47kΩ | R1,R2,R3,R6 | R0402 | 47kΩ | 0402WGF4702TCE | UNI-ROYAL(厚声) | C25792 | LCSC | 0402WGF4702TCE | Type:Thick Film Resistors Resistance:47kΩ Tolerance:±1% Tolerance:±1% Power(Watts): Overload Voltage (Max): Temperature Coefficient:±100ppm/℃ Temperature Coefficient:±100ppm/℃ Operating Temperature Range:-55℃~+155℃ Operating Temperature Range:-55℃~+155℃
17 | 2 | 2.2kΩ | R4,R5 | R0402 | 2.2kΩ | 0402WGF2201TCE | UNI-ROYAL(厚声) | C25879 | LCSC | 0402WGF2201TCE | Type:Thick Film Resistors Resistance:2.2kΩ Tolerance:±1% Tolerance:±1% Power(Watts): Overload Voltage (Max): Temperature Coefficient:±100ppm/℃ Temperature Coefficient:±100ppm/℃ Operating Temperature Range:-55℃~+155℃ Operating Temperature Range:-55℃~+155℃
18 | 2 | 33Ω | R7,R8 | R0402 | 33Ω | 0402WGF330JTCE | UNI-ROYAL(厚声) | C25105 | LCSC | 0402WGF330JTCE | Type:Thick Film Resistors Resistance:33Ω Tolerance:±1% Tolerance:±1% Power(Watts): Overload Voltage (Max): Temperature Coefficient:±100ppm/℃ Temperature Coefficient:±100ppm/℃ Operating Temperature Range:-55℃~+155℃ Operating Temperature Range:-55℃~+155℃
19 | 5 | 220Ω | R9,R14,R15,R19,R20 | R0603 | 220Ω | 0603WAF2200T5E | UNI-ROYAL(厚声) | C22962 | LCSC | 0603WAF2200T5E | Type:Thick Film Resistors Resistance: Tolerance:±1% Tolerance:±1% Power(Watts): Overload Voltage (Max): Temperature Coefficient:±100ppm/℃ Temperature Coefficient:±100ppm/℃ Operating Temperature Range:-55℃~+155℃ Operating Temperature Range:-55℃~+155℃
20 | 2 | 5.1kΩ | R10,R11 | R0603 | 5.1kΩ | 0603WAF5101T5E | UNI-ROYAL(厚声) | C23186 | LCSC | 0603WAF5101T5E | Type:Thick Film Resistors Resistance:5.1kΩ Tolerance:±1% Tolerance:±1% Power(Watts): Overload Voltage (Max): Temperature Coefficient:±100ppm/℃ Temperature Coefficient:±100ppm/℃ Operating Temperature Range:-55℃~+155℃ Operating Temperature Range:-55℃~+155℃
21 | 2 | 4.7kΩ | R12,R13 | R0603 | 4.7kΩ | 0603WAF4701T5E | UNI-ROYAL(厚声) | C23162 | LCSC | 0603WAF4701T5E | Type:Thick Film Resistors Resistance:4.7kΩ Tolerance:±1% Tolerance:±1% Power(Watts): Overload Voltage (Max): Temperature Coefficient:±100ppm/℃ Temperature Coefficient:±100ppm/℃ Operating Temperature Range:-55℃~+155℃ Operating Temperature Range:-55℃~+155℃
22 | 2 | 10kΩ | R16,R21 | R0402 | 10kΩ | ERJ2GEJ103X | PANASONIC(松下) | C278577 | LCSC | ERJ2GEJ103X | Type:Thick Film Resistor Resistance:10kΩ Tolerance:±5% Tolerance:±5% Power(Watts):100mW Voltage-Supply(Max):100V Temperature Coefficient:±200ppm/℃ Temperature Coefficient:±200ppm/℃ Operating Temperature:-55℃~+155℃ Operating Temperature:-55℃~+155℃
23 | 1 | 33Ω | R17 | R1206 | 33Ω | AS0606J0330T5E | UNI-ROYAL(厚声) | C966057 | LCSC | AS0606J0330T5E_C966057 | Type:Thick Film Resistors Resistance: Tolerance:±5% Tolerance:±5% Power(Watts): Voltage-Supply(Max): Temperature Coefficient:±100ppm/℃ Temperature Coefficient:±100ppm/℃ Operating Temperature:-55℃~+155℃ Operating Temperature:-55℃~+155℃
24 | 1 | 2.2kΩ | R18 | R0603 | 2.2kΩ | 0603WAF2201T5E | UNI-ROYAL(厚声) | C4190 | LCSC | 0603WAF2201T5E_C4190 | Type:Thick Film Resistors Resistance:2.2kΩ Tolerance:±1% Tolerance:±1% Power(Watts): Overload Voltage (Max): Temperature Coefficient:±100ppm/℃ Temperature Coefficient:±100ppm/℃ Operating Temperature Range:-55℃~+155℃ Operating Temperature Range:-55℃~+155℃
25 | 1 | 1MΩ | R22 | R0603 | 1MΩ | 0603WAF1004T5E | UNI-ROYAL(厚声) | C22935 | LCSC | 0603WAF1004T5E | Type:Thick Film Resistors Resistance:1MΩ Tolerance:±1% Tolerance:±1% Power(Watts): Overload Voltage (Max): Temperature Coefficient:±100ppm/℃ Temperature Coefficient:±100ppm/℃ Operating Temperature Range:-55℃~+155℃ Operating Temperature Range:-55℃~+155℃
26 | 1 | 80.6kΩ | RLIM1 | R0402 | 80.6kΩ | RC0402FR-0780K6L | YAGEO(国巨) | C155698 | LCSC | RC0402FR-0780K6L | Type:Thick Film Resistors Resistance: Tolerance:±1% Tolerance:±1% Power(Watts): Overload Voltage (Max): Temperature Coefficient:±100ppm/℃ Temperature Coefficient:±100ppm/℃ Operating Temperature Range:-55℃~+155℃ Operating Temperature Range:-55℃~+155℃
27 | 2 | TS-1101-C-W | SW1,SW2 | SW-SMD_L6.0-W3.3-LS8.0 |  | TS-1101-C-W | XKB Connectivity(中国星坤) | C318938 | LCSC | TS-1101-C-W | Circuit:SPST Actuator Style:Rectangle button Operating Force:260gf Mounting Style:Brick nogging Switch Length:6mm Switch Width:3.6mm Switch Height:2.5mm Strike Gundam:不带 Contact Current:50mA Voltage Rating (AC):- Voltage Rating (DC):12V Power Rating:- Ins
28 | 1 | ESP32-C6-MINI-1-N4 | U1 | WIFIM-SMD_61P-L16.6-W13.2-P0.80-ESP32-C6-MINI-1-N4 |  | ESP32-C6-MINI-1-N4 | ESPRESSIF(乐鑫) | C5736265 | LCSC | ESP32-C6-MINI-1-N4
29 | 1 | ST1L05APU33R | U2 | DFN-6_L3.0-W3.0-P0.95-BL-EP-1 |  | ST1L05APU33R | ST(意法半导体) | C283488 | LCSC | ST1L05APU33R | Output Type:Fixed Maximum Input Voltage:7V Output Voltage:3.3V Output Voltage:3.3V Output Current:1.3A Power Supply Rejection Ratio (PSRR):65dB@(120Hz) Dropout Voltage:500mV@(1.3A) standby current:650uA Feature:ESD Protection；Low ESR；Thermal Protection(TS
30 | 1 | VL53L5CXV0GC/1 | U3 | LGA-16_L6.4-W3.0_VL53L5CXV0GC-1 |  | VL53L5CXV0GC/1 | ST(意法半导体) | C3178303 | LCSC | VL53L5CXV0GC/1 | Supply Voltage:2.8V~3.3V Supply Voltage:2.8V~3.3V Iinearity Range:4m Iinearity Range:4m
31 | 1 | TYPE-C 16P LTH8.8 | U4 | USB-C-SMD_TYPE-C-16P-LTH8.8 |  | TYPE-C 16P LTH8.8 | SHOU HAN(首韩) | C5187469 | LCSC | TYPE-C 16P LTH8.8 | Connector Type:Type-C Standard:USB 3.1 Gender:Female Mounting Style:Standing paste Number of Contacts:16P Number of Ports:1 Current Rating - Power (Max):5A Contact Material:- Contact Plating:- Operating Temperature Range:-40℃~+85℃ Operating Temperature Ra
32 | 1 | TPS2121RUXR | U5 | VQFN-HR-12_L2.5-W2.0-P0.50-BL |  | TPS2121RUXR | TI(德州仪器) | C485916 | LCSC | TPS2121RUXR
33 | 1 | MAX40200AUK+T | U6 | TSOT-23-5_L2.9-W1.6-P0.95-LS2.8-BL |  | MAX40200AUK+T | ADI(亚德诺)/MAXIM(美信) | C2649430 | LCSC | MAX40200AUK+T

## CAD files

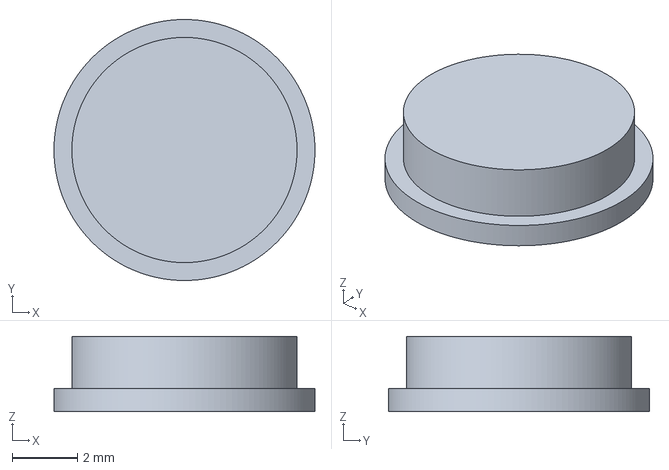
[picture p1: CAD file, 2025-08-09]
HARDWARE/Rev.2/Case_IR_Lens_VisionGuard_Rev_2.3mf
8.00 x 8.00 x 2.30 mm

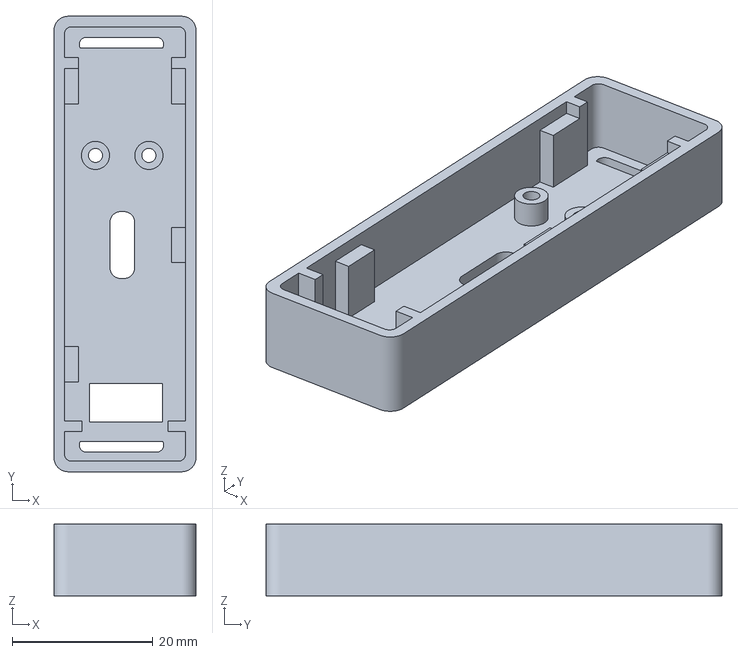
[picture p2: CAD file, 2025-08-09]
HARDWARE/Rev.2/Case_Back_Cover_VisionGuard_Rev_2.3mf
20.2 x 64.8 x 10.2 mm

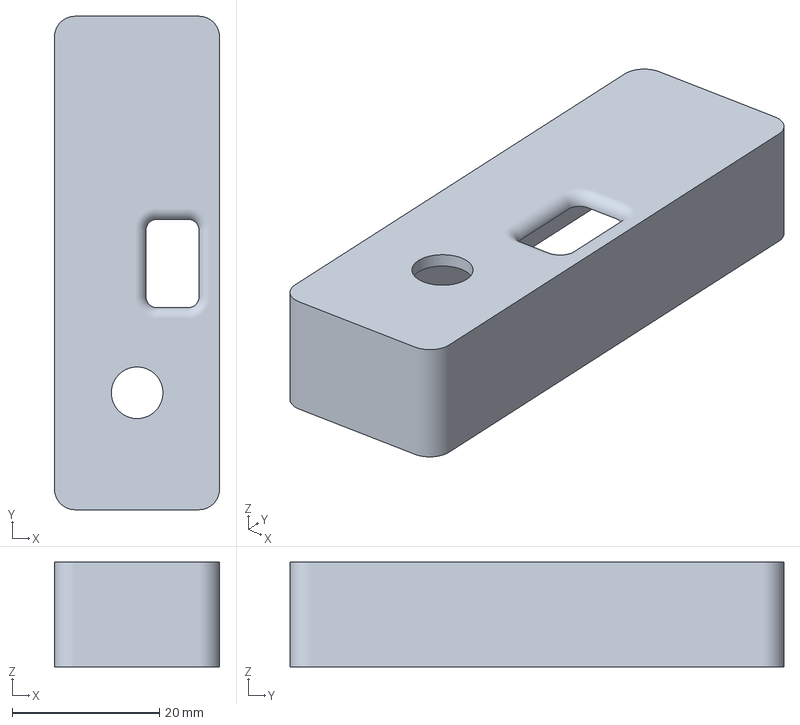
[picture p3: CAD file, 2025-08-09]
HARDWARE/Rev.2/Case_Front_Cover_VisionGuard_Rev_2.3mf
22.4 x 67.0 x 14.2 mm

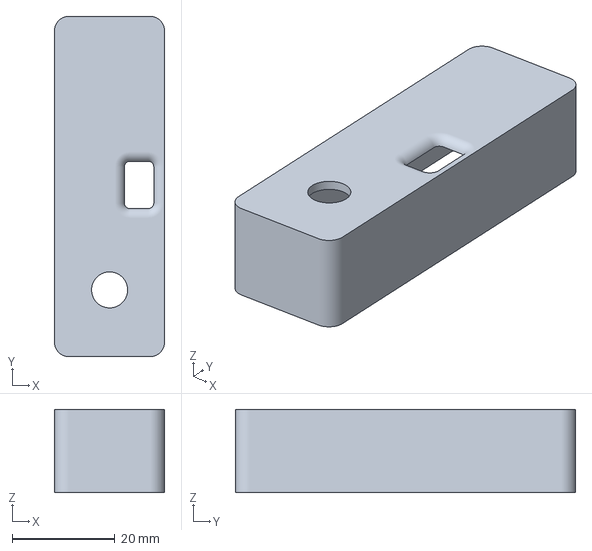
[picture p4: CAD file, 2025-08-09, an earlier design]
HARDWARE/Rev.1/Case_Front_Cover_VisionGuard_Rev_1.3mf
21.4 x 66.2 x 16.2 mm

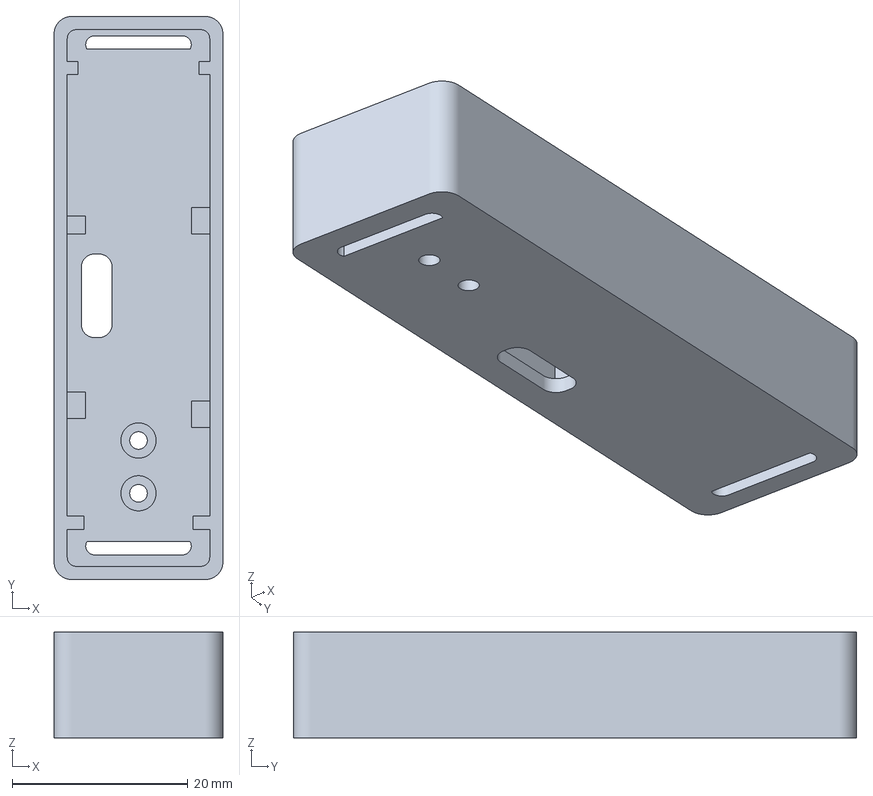
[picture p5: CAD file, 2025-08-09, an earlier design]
HARDWARE/Rev.1/Case_Back_Cover_VisionGuard_Rev_1.3mf
19.2 x 64.0 x 12.0 mm

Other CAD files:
HARDWARE/Rev.1/Case_IR Lens_VisionGuard_Rev_1.3mf

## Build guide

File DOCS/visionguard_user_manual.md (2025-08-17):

# VisionGuard User Manual

## Overview

VisionGuard is an intelligent child safety monitoring system that automatically controls television access based on viewing distance. The device uses advanced Time-of-Flight sensing technology to monitor viewer proximity and executes customizable actions via infrared commands when unsafe viewing distances are detected.

## What's in the Box

- VisionGuard device (Revision 1 or 2)
- USB-C cable for power and programming
- Quick start guide

## Initial Setup

### 1. Physical Installation

**Mounting Position:**
- Mount the device near your TV with the sensor facing the viewing area
- Ensure clear line-of-sight between the sensor and typical viewing positions
- Position the IR LED to face your TV's IR receiver (usually front-center of TV)
- Connect power via USB-C cable

**Optimal Placement:**
- Height: Same level as TV screen center
- Distance from TV: 1-2 feet to the side
- Avoid obstacles between sensor and seating area

### 2. Network Configuration

**WiFi Setup:**
1. Power on the device
2. Connect to the "VisionGuard Rev.1 AP" network (password: 12345678)
3. Configure your home WiFi network through the captive portal
4. Device will restart and connect to your network

**Web Interface Access:**
- Find the device IP address in your router's DHCP table
- Open web browser and navigate to the device IP
- Bookmark this page for easy access

## Core Features

### Distance Monitoring

**How it Works:**
- Continuously measures distance to viewers using Time-of-Flight sensor
- Supports detection range from 0.3m to 4.0m
- Updates 5 times per second for responsive monitoring
- Uses dual-threshold system to prevent false triggers

**Detection Zones:**
- **Close Zone**: When viewer is too close to TV (default: 0.8m)
- **Safe Zone**: Optimal viewing distance (between thresholds)  
- **Far Zone**: When viewer moves away (default: 1.0m)

### Automatic TV Control

**Supported Actions:**
- **Near Actions** (child too close): Mute, Power Off, Switch inputs
- **Far Actions** (child moved away): Unmute, Power On, Restore previous

**IR Protocol Support:**
- Primary: LG TV commands (pre-configured)
- Compatible with most modern TV brands
- Configurable repeat count for reliability

## Configuration Guide

### Basic Settings

**Distance Thresholds:**
- **Close Threshold**: Distance considered "too close" (0.3m - 2.0m)
- **Far Threshold**: Distance when child has "moved away" (0.5m - 3.0m)
- *Note: Far threshold must be greater than close threshold*

**Timing Settings:**
- **Close Grace Period**: Delay before taking action (1-30 seconds)
- **Far Hold Time**: How long to wait before restoration (1-30 seconds)

**IR Settings:**
- **Repeat Count**: Number of IR command repetitions (1-5)
- Higher values improve reliability but may cause TV lag

### Action Configuration

**Near Actions (When Child Too Close):**
- Mute - Silence TV audio
- Power Off - Turn TV off completely  
- Switch to HDMI1/2/3 - Change to safe content input
- Switch to TV - Change to broadcast TV
- Show Input List - Display input selection menu
- Do Nothing - Monitor only, no action

**Far Actions (When Child Moves Away):**
- Unmute - Restore TV audio
- Power On - Turn TV back on
- Switch to Previous - Return to previous input
- Switch to HDMI1/2/3 - Change to specific input
- Exit/Back - Navigate back in TV menu
- Do Nothing - No restoration action

## Daily Operation

### Enabling Protection

1. Access the web interface
2. Toggle "Protection Enabled" to ON
3. Green indicator shows system is active
4. System begins monitoring immediately

### Normal Operation Flow

1. **Standby**: System monitors distance continuously
2. **Detection**: Child detected in close zone
3. **Grace Period**: Countdown timer starts (configurable delay)
4. **Action**: If still too close, executes configured near action
5. **Recovery**: When child moves to safe distance, executes far action

### Manual Controls

**Test Buttons:**
- **Test Near Action**: Manually trigger close action
- **Test Far Action**: Manually trigger recovery action
- **Force Mute**: Emergency mute button
- **Force Input**: Show TV input selection

**System Control:**
- **Restart**: Reboot the device
- **Protection Toggle**: Enable/disable monitoring

## Advanced Features (Revision 2)

### Multi-Zone Detection
- 64-zone sensing array (8×8 grid)
- Simultaneous tracking of multiple children
- Zone-specific configuration options
- Enhanced spatial accuracy

### Grove Expansion Port
- Connect additional sensors and modules
- I2C interface supports 300+ Grove modules
- Examples: displays, environmental sensors, additional outputs
- Automatic device discovery and configuration

### Enhanced Power Management
- Dual power input (USB-C + Grove)
- Automatic power source switching
- Enhanced surge and overcurrent protection

## Troubleshooting

### Common Issues

**"No object detected" constantly:**
- Check sensor mounting - ensure clear view of seating area
- Verify sensor is not blocked by objects
- Check if child is within detection range (0.3-4.0m)

**IR commands not working:**
- Verify IR LED is pointing toward TV IR receiver
- Check IR repeat count setting (try increasing to 3-5)
- Ensure TV brand compatibility (optimized for LG)
- Test with manual "Force Mute" button

**False triggers:**
- Adjust grace period (increase to 3-5 seconds)
- Fine-tune distance thresholds
- Check for moving objects in sensor field of view

**WiFi connection issues:**
- Reset to AP mode by holding reset during power-on
- Reconnect using "VisionGuard Rev.1 AP" network
- Check WiFi signal strength in device location

### System Status

**Web Interface Indicators:**
- **Target Distance**: Current measured distance
- **Uptime**: How long device has been running
- **WiFi Signal**: Connection strength
- **MCU Temperature**: Internal temperature monitoring

**Log Messages:**
- View real-time system logs through web interface
- Monitor protection state changes
- Track IR command transmission

### Factory Reset

1. Power off the device
2. Hold down any physical button (if available) while powering on
3. Or reset network settings through web interface
4. Reconfigure WiFi and all settings

## Safety Information

### IR Safety
- Device uses Class 1 IR LED (eye-safe)
- 940nm wavelength (invisible infrared)
- Pulsed transmission minimizes exposure

### Electrical Safety  
- Use only provided USB-C cable
- Operating temperature: -10°C to +60°C
- Keep away from moisture and extreme heat

### Child Safety Notes
- Device is a parental aid, not a substitute for supervision
- Regularly verify proper operation and calibration
- Consider multiple monitoring methods for comprehensive safety

## Technical Specifications

**Detection Performance:**
- Range: 0.3m to 4.0m
- Accuracy: ±30mm at 1m distance
- Response time: <300ms
- False positive rate: <1%

**Connectivity:**
- WiFi: 802.11 b/g/n/ax (2.4GHz)
- Security: WPA3/WPA2 Personal
- Range: 30m typical indoor

**Power Requirements:**
- Input: 5V via USB-C
- Consumption: 65-85mA normal operation
- Peak: 180-200mA during IR transmission

## Support

For additional support:
- Check device logs through web interface
- Verify latest firmware through OTA updates
- Consult technical documentation for advanced configuration

---

*Manual Version 1.0 - Compatible with VisionGuard Revision 1 & 2*

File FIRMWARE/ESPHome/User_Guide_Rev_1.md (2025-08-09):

# VisionGuard Rev.1 — ESPHome + ToF (VL53L3CX) + IR (LG) 

This document explains **how the configuration works (for maintainers)** and **what the end user sees/does on the device web page**.

---

## 1) What VisionGuard does (at a glance)
- Reads distance from a **VL53L3CX** ToF sensor, smoothed with **EMA** to suppress noise.
- Implements a **two‑state safety FSM**:  
  **STANDBY → (near for X s) → ACTIVE → (far/no‑object for Y s) → STANDBY**.
- When entering **ACTIVE** (child too close), it runs a configurable **“Near Action”** (e.g., **Mute**, **Power Off**, **Switch input**).  
  When returning to **STANDBY**, it runs a configurable **“Far Action”** (e.g., **Unmute**, **Power On**, **Back**).
- Sends **LG IR** codes via `remote_transmitter` on GPIO4. Actions are queued and retried with a configurable repeat count.

> Defaults: **Near = Mute**, **Far = Unmute**, **Close = 0.80 m**, **Far = 1.00 m**, **Close grace = 2 s**, **Far hold = 2 s**, **IR repeats = 3**.

---

## 2) Architecture (ESPHome maintainer view)

### 2.1 Platform
- **Board:** `esp32-c6-devkitm-1`
- **Framework:** ESP‑IDF (currently `version: latest`)
- **Web UI:** `web_server: version: 3`

### 2.2 Networking
- **Wi‑Fi:** `wifi.networks[0]` from secrets; AP fallback `'{device_name} AP'` (`password: 12345678`).
- **API/OTA:** Enabled; `api.reboot_timeout: 0s` (stays connected to HA even if idle).
- **Time:** SNTP using `Asia/Dubai` and three servers (two stratum servers + pool).

### 2.3 ToF sensing
- **Bus:** I²C on `GPIO6/7` at `38 kHz` (scanning on).
- **Sensor hub:** `vl53l3cx:` component (external_components `my_components`), device address `0x29`.
- **Measurement:** `distance_mode: MEDIUM`, `timing_budget: 80 ms`, `inter_measurement_period: 100 ms`, driver `update_interval: 200 ms`.
- **Smoothing:** `exponential_moving_average: alpha: 0.1, send_every: 4` (≈0.8–1.0 Hz publishes).
- **Entity:** `sensor.primary_target` (“Target Distance”, m, 3 decimals).

### 2.4 IR transmit
- **Transmitter:** `remote_transmitter` on **GPIO4**, `carrier_duty_percent: 50%`.  
  LG protocol frames are sent via `remote_transmitter.transmit_lg` with **repeat** block:
  `repeat.times = ir_repeat_count`, `wait_time: 50 ms` (50,000 µs).

### 2.5 State machine & timers
- `switch.guard_enabled` gates all automation.
- `globals.protection_active_state` is the current FSM state (false=STANDBY, true=ACTIVE).
- **On each distance publish (`sensor.primary_target.on_value`)**:
  - **Near region:** `d < close_threshold_m` → start **near_guard_timer** once; stop **far_hold_timer**.
  - **Far region:** `isnan(d) || d > far_threshold_m` → start **far_hold_timer** once; stop **near_guard_timer**.
  - **Deadband:** between thresholds → stop both timers (no pending fire).
- **near_guard_timer:** wait `close_grace_s`; re‑check *still near* and guard **not already ACTIVE** → set ACTIVE and `execute_near_action`.
- **far_hold_timer:** wait `far_hold_s`; re‑check *still far or no object* and guard **ACTIVE** → clear ACTIVE and `execute_far_action`.

### 2.6 User‑configurable entities
These are inputs the user can tune from the device web page or Home Assistant:

| Type | ID | Display Name | Range / Options | Default |
|---|---|---|---|---|
| `switch` | `guard_enabled` | Protection Enabled | On/Off | Off |
| `number` | `close_threshold_m` | Close Threshold (m) | 0.30–2.00 (0.05 step) | 0.80 |
| `number` | `far_threshold_m` | Far Threshold (m) | 0.50–3.00 (0.05 step) | 1.00 |
| `number` | `close_grace_s` | Close Grace (s) | 1–30 (1 step) | 2 |
| `number` | `far_hold_s` | Far Hold (s) | 1–30 (1 step) | 2 |
| `number` | `ir_repeat_count` | IR Repeat Count | 1–5 (1 step) | 3 |
| `select` | `near_action` | Near Action (Child Too Close) | *Mute, Power Off, Switch to HDMI1/2/3, Switch to TV, Home Dashboard, Show Input List, Exit/Back, Do Nothing* | Mute |
| `select` | `far_action` | Far Action (Child Moved Away) | *Unmute, Power On, Switch to Previous, Switch to HDMI1/2/3, Switch to TV, Home Dashboard, Exit/Back, Do Nothing* | Unmute |

Additional telemetry:
- `sensor.uptime`, `sensor.internal_temperature`, `sensor.wifi_signal`
- `text_sensor.wifi_info.ip_address`

### 2.7 Buttons (for testing/ops)
- **Test Near Action** → runs `execute_near_action` immediately (ignores distance).
- **Test Far Action** → runs `execute_far_action` immediately.
- **Force Mute** → sends LG Mute via the action mapper (queued).
- **Force Input** → opens LG input list via the action mapper (queued).

### 2.8 IR action mapping
`script.send_lg_command_mapped` translates a selected action to one of these LG commands (all are emitted by `script.send_lg_ir` with repeats):

| Action(s) | LG Command | Notes |
|---|---|---|
| Power On / Power Off | `power` | **Toggle code** (0x20DF10EF). If you need discrete On/Off, the TV must support them; otherwise this toggles. |
| Mute / Unmute | `mute` | Toggle mute (0x20DF906F). |
| Show Input List | `input` | 0x20DFD02F. |
| Switch to HDMI1 / 2 / 3 | `hdmi1` / `hdmi2` / `hdmi3` | 0x20DF738C / 0x20DF33CC / 0x20DF9966. |
| Switch to TV (Tuner) | `tv` | 0x20DF0FF0. |
| Home Dashboard | `home` | 0x20DFDA25. |
| Exit/Back / Switch to Previous | `back` | 0x20DF14EB. |

> The **repeat count** multiplies the command reliability on fussy sets. Start at 2–3; increase only if needed.

### 2.9 Boot‑time safety
On boot, if `close_threshold_m >= far_threshold_m`, the config nudges `far_threshold_m` up by +0.10 m and logs a warning.

---

## 3) End‑user guide (what you see on the device web page)

> Open a browser to the device’s IP (shown on the page as **IP Address**). The UI is the standard ESPHome Web Server v3.

### Main controls
1. **Protection Enabled (switch):** turn the safety automation on/off. When Off, the system won’t trigger any actions.
2. **Target Distance (sensor):** live distance in meters (smoothed). Use this to calibrate thresholds.
3. **Near/Far Thresholds:** set the “too close” and “safe” distances. Keep **Far > Close**. A dead‑band between them prevents chattering.
4. **Close Grace / Far Hold:** how long to wait *continuously* in each zone before acting.
5. **Near Action / Far Action:** pick what happens when entering/leaving the “too close” state.
6. **IR Repeat Count:** number of protocol‑level repeats for each IR send.
7. **Test Buttons:** try actions without moving in front of the sensor (useful for setup).

### Typical setup flow
1. **Connect Wi‑Fi** (first boot may expose an AP `VisionGuard Rev.1 AP`). Then open the device web page.
2. **Enable Protection.**
3. **Stand at the desired minimum distance** and read *Target Distance*. Set **Close Threshold** a bit higher than that value (e.g., add 0.05–0.10 m).
4. **Walk back to the “safe” distance** you want. Set **Far Threshold** slightly beyond that.
5. Choose **Near Action** (e.g., *Mute* or *Power Off*) and **Far Action** (e.g., *Unmute* or *Power On*).
6. Set **Close Grace** (~2–3 s) and **Far Hold** (~2–3 s) to avoid nuisance triggers.
7. Use **Test Near/Far Action** to verify the TV reacts. If IR is intermittent, raise **IR Repeat Count** to 3–4.
8. Confirm that **leaving the field of view counts as Far** (this build treats “no object” as Far by design).

### Status & diagnostics
- The page also shows **Uptime**, **MCU Temperature**, **Wi‑Fi Signal**, and **IP Address**.
- The device logs status lines every 60 s (e.g., *Protection ON – Distance: 0.75 m* or *Protection ON – No object detected*), plus action traces.
- If needed, use the **OTA** tab (via ESPHome/HA) for upgrades and the **log viewer** for live debugging.

---

## 4) Customization & maintenance notes

- **LG‑only IR by default.** To support another brand, replace the `transmit_lg` blocks with the appropriate protocol (e.g., `transmit_nec`) and codes, keeping the same mapper structure.
- **Carrier tuning.** If certain TVs are picky, you can add `frequency: 38kHz` under `remote_transmitter` to match common LG remotes.
- **EMA cadence.** `send_every: 4` keeps automation responsive while filtering noise. If your scene is jittery, try `alpha: 0.08–0.12` before increasing `send_every`.
- **Deadband behavior.** The automation cancels pending timers in the deadband to avoid stale fires. If you want “latch on first entry,” move the cancelation to the opposite edge; otherwise keep as‑is.
- **No‑object semantics.** This build treats **no object as FAR** for the “move away” action. To change that, edit the FAR condition and post‑delay check to drop `isnan(d)`.

---

## 5) Troubleshooting

- **Actions don’t fire:** Ensure **Protection Enabled** is ON. Check that **Close < Far** (the device will auto‑nudge on boot if not). Watch the logs for “Executing Near/Far Action…” lines.
- **IR unreliable:** Increase **IR Repeat Count**; ensure clear line‑of‑sight to the TV’s IR receiver; consider adding `frequency: 38kHz` under `remote_transmitter`.
- **Triggers feel laggy:** Reduce **Close Grace / Far Hold** or lower `send_every` (more frequent publishes). Don’t remove EMA entirely; noise will cause oscillations.
- **Too sensitive near threshold:** Raise **Close Threshold** or increase **Close Grace** by 1–2 s.
- **Not unmuting when the child leaves FOV:** This build already counts **no object** as FAR. If behavior differs, check the logs to ensure the sensor actually goes to “no object” (NaN).

---

## 6) Files & IDs (quick reference)
- Device name: **VisionGuard Rev.1** (`vision-guard-rev-1`)
- Key IDs: `primary_target`, `guard_enabled`, `protection_active_state`, `near_guard_timer`, `far_hold_timer`, `execute_near_action`, `execute_far_action`, `send_lg_command_mapped`, `send_lg_ir`.

—

*Maintainer tip:* keep a copy of the IR code table in comments next to the mapper. If you add new actions, extend `select` options and update `send_lg_command_mapped` to route them.

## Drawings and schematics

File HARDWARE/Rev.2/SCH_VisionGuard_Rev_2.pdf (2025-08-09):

IO21 27 IO22 28 IO23 29 RXD0 30 TXD0 31 NC 32 NC 33 NC 34 NC 35 GND 36 GND 37 GND 38 GND 39 GND 40 GND 41 GND 42 GND 43 GND 44 GND 45 GND 46 GND 47 GND 48 GND 49 GND 50 GND 51 GND 52 GND 53

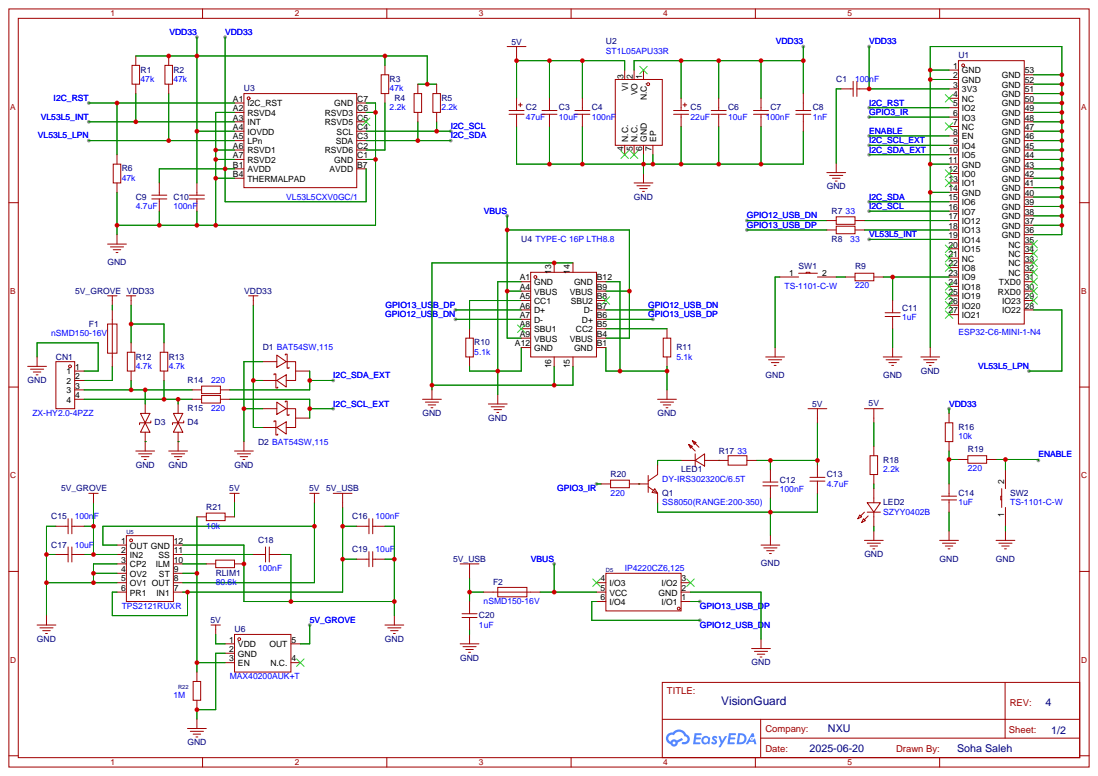
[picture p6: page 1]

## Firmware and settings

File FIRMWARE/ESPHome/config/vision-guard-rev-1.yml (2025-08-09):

esphome:
  name: vision-guard-rev-1
  friendly_name: 'VisionGuard Rev.1'
  on_boot:
    priority: 600
    then:
      - logger.log: "VisionGuard Child Safety System Starting..."
      - delay: 3s
      - logger.log: "System Ready"
      - lambda: |-
          if (id(close_threshold_m).state >= id(far_threshold_m).state) {
            ESP_LOGW("config", "Adjusting thresholds: close >= far, nudging far up");
            id(far_threshold_m).publish_state(id(close_threshold_m).state + 0.10f);
          }

substitutions:
  device_name: 'VisionGuard Rev.1'

esp32:
  board: esp32-c6-devkitm-1
  framework:
    type: esp-idf
    version: latest

# Logging configuration
logger:
  level: INFO

api:
  reboot_timeout: 0s

ota:
  - platform: esphome

wifi:
  networks:
  - ssid: !secret wifi_ssid
    password: !secret wifi_password

  ap:
    ssid: '${device_name} AP'
    password: '12345678'

captive_portal:

web_server:
  port: 80
  version: 3

time:
  - platform: sntp
    id: sntp_time
    timezone: Asia/Dubai
    servers:
     - '193.204.114.232'
     - '129.6.15.30'
     - '0.asia.pool.ntp.org'
    # on_time:
    # TODO: scheduling actions for the device

i2c:
  - id: bus_a
    sda: GPIO6
    scl: GPIO7
    scan: true
    frequency: 38kHz # 50kHz

external_components:
  - source:
      type: local
      path: my_components
    components: [vl53l3cx]

# Configure the VL53L3CX sensor hub
vl53l3cx:
  - id: tof_sensor
    address: 0x29  # Default 7-bit I2C address
    i2c_id: bus_a

    # Basic configuration
    # Distance measurement mode, affects max range vs. ambient immunity: SHORT Up to 1.36m, MEDIUM Up to 2.90m, LONG Up to 3.60m
    distance_mode: MEDIUM               # default MEDIUM
    # Measurement timing budget, 20ms to 1000ms, Higher = better accuracy, slower, Keep <= inter_measurement_period
    timing_budget: 80ms                 # default 33ms
    # Time between measurement starts in the sensor (must be >= timing_budget)
    inter_measurement_period: 100ms     # default timing_budget + 5
    # Sensor status publish interval. The sensor itself always runs continuously internally, must be >= inter_measurement_period
    update_interval: 200ms              # default 100ms

    ### Advanced signal processing configuration for multi-target separation, Accuracy/SNR tuning
    # Minimum signal rate (MCPS) to accept a range; lower is more permissive
    signal_rate_limit: 0.1              # default 0.1
    # Sigma threshold (mm); higher tolerates noisier returns
    sigma_threshold: 60.0               # default 50
    # Smudge correction mode: DISABLE | CONTINUOUS | SINGLE | DEBUG
    smudge_correction_mode: CONTINUOUS  # default CONTINUOUS
    # Multi-target ordering: DISTANCE (closest first) | SIGNAL_STRENGTH (strongest first)
    target_order: DISTANCE              # default DISTANCE

    # Multi-target separation & histogram tuning
    # merge_threshold: lower separates nearby targets more.
    merge_threshold: 12000              # default 15000
    # hist_noise_threshold: lower retains weaker secondary peaks.
    hist_noise_threshold: 50            # default 50
    # hist_merge: set false only for debugging edge cases
    hist_merge: true                    # default True
    # hist_merge_max_size:  (1..16)
    hist_merge_max_size: 8              # default 8
  
    # GPIO pin configuration (optional)
    xshut_pin:
      number: GPIO3
      mode:
        output: true
        pullup: true
    interrupt_pin:
      number: GPIO2
      mode:
        input: true
        pullup: false

# ---------- IR Transmitter Configuration ----------
remote_transmitter:
  id: ir_remote
  pin: GPIO4
  carrier_duty_percent: 50%
  # rmt_symbols: 96  

# ---------- Global Variables ----------
globals:
  - id: last_valid_distance
    type: float
    restore_value: no
    initial_value: '2.0'
  
  - id: protection_active_state
    type: bool
    restore_value: no
    initial_value: 'false'
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

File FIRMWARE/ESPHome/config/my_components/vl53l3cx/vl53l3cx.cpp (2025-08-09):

#include "vl53l3cx.h"
#include "esphome/core/log.h"
#include "esphome/core/helpers.h"
#include <cstring>

// Include ST library headers
extern "C" {
#include "vl53lx_api.h"
#include "vl53lx_api_core.h"
}

// External function to set component for platform layer
extern void vl53lx_set_i2c_component(esphome::vl53l3cx::VL53L3CXComponent *component);

namespace esphome {
namespace vl53l3cx {

static const char *const TAG = "vl53l3cx";

static const char* get_error_string(VL53LX_Error error) {
  switch(error) {
    case 0: return "NONE";
    case -1: return "CALIBRATION_WARNING";
    case -2: return "MIN_CLIPPED";
    case -3: return "UNDEFINED";
    case -4: return "INVALID_PARAMS";
    case -5: return "NOT_SUPPORTED";
    case -6: return "RANGE_ERROR";
    case -7: return "TIME_OUT";
    case -8: return "MODE_NOT_SUPPORTED";
    case -9: return "BUFFER_TOO_SMALL";
    case -10: return "COMMS_BUFFER_TOO_SMALL";
    case -11: return "GPIO_NOT_EXISTING";
    case -12: return "GPIO_FUNCTIONALITY_NOT_SUPPORTED";
    case -13: return "CONTROL_INTERFACE";
    case -14: return "INVALID_COMMAND";
    case -15: return "DIVISION_BY_ZERO";
    case -16: return "REF_SPAD_INIT";
    case -17: return "GPH_SYNC_CHECK_FAIL";
    case -18: return "STREAM_COUNT_CHECK_FAIL";
    case -19: return "GPH_ID_CHECK_FAIL";
    case -20: return "ZONE_STREAM_COUNT_CHECK_FAIL";
    case -21: return "ZONE_GPH_ID_CHECK_FAIL";
    case -22: return "XTALK_EXTRACTION_NO_SAMPLE_FAIL";
    case -23: return "XTALK_EXTRACTION_SIGMA_LIMIT_FAIL";
    case -24: return "OFFSET_CAL_NO_SAMPLE_FAIL";
    case -25: return "OFFSET_CAL_NO_SPADS_ENABLED_FAIL";
    case -26: return "ZONE_CAL_NO_SAMPLE_FAIL";
    case -27: return "TUNING_PARM_KEY_MISMATCH";
    case -28: return "WARNING_REF_SPAD_CHAR_NOT_ENOUGH_SPADS";
    case -29: return "WARNING_REF_SPAD_CHAR_RATE_TOO_HIGH";
    case -30: return "WARNING_REF_SPAD_CHAR_RATE_TOO_LOW";
    case -31: return "WARNING_OFFSET_CAL_MISSING_SAMPLES";
    case -32: return "WARNING_OFFSET_CAL_SIGMA_TOO_HIGH";
    case -33: return "WARNING_OFFSET_CAL_RATE_TOO_HIGH";
    case -34: return "WARNING_OFFSET_CAL_SPAD_COUNT_TOO_LOW";
    case -35: return "WARNING_ZONE_CAL_MISSING_SAMPLES";
    case -36: return "WARNING_ZONE_CAL_SIGMA_TOO_HIGH";
    case -37: return "WARNING_ZONE_CAL_RATE_TOO_HIGH";
    case -38: return "WARNING_XTALK_NO_SAMPLES_FOR_GRADIENT";
    case -39: return "WARNING_XTALK_SIGMA_LIMIT_FOR_GRADIENT";
    case -40: return "WARNING_XTALK_MISSING_SAMPLES";
    case -41: return "NOT_IMPLEMENTED";
    case -42: return "PLATFORM_SPECIFIC_START";
    default: return "UNKNOWN";
  }
}

void VL53L3CXComponent::setup() {
  ESP_LOGCONFIG(TAG, "Setting up VL53L3CX...");
  
  // Initialize calibration preference object (persist in flash)
  // Use a stable type key based on I2C address to support multiple sensors
  if (global_preferences != nullptr) {
    uint32_t pref_type = 0x564C5300u | (uint32_t)(this->address_ & 0x7Fu); // 'VLS' + addr
    this->calibration_pref_ = global_preferences->make_preference<VL53LX_CalibrationData_t>(pref_type, true);
  }
  
  // Set this component for platform functions to use
  vl53lx_set_i2c_component(this);
  ESP_LOGD(TAG, "Platform component set");
  
  // Setup GPIO pins
  this->setup_gpio_pins_();
  
  // Reset device if XSHUT pin available
  this->reset_device_();
  
  // Allocate device structure
  ESP_LOGD(TAG, "Allocating device structure (size: %u bytes)", sizeof(VL53LX_Dev_t));
  this->device_ = new VL53LX_Dev_t();
  if (!this->device_) {
    ESP_LOGE(TAG, "Failed to allocate device structure");
    this->mark_failed();
    return;
  }
  memset(this->device_, 0, sizeof(VL53LX_Dev_t));
  this->device_->i2c_slave_address = this->address_ << 1;  // Convert 7-bit to 8-bit
  ESP_LOGD(TAG, "Device structure allocated, I2C address: 0x%02X", this->device_->i2c_slave_address);
  
  // Load calibration data (if available)
  bool has_calibration = this->load_calibration_data_();
  
  // Initialize the device
  if (!this->initialize_device_()) {
    ESP_LOGE(TAG, "Failed to initialize VL53L3CX");
    this->mark_failed();
    return;
  }
  
  // Log calibration status
  if (has_calibration) {
    ESP_LOGI(TAG, "Using stored calibration data");
  } else {
    ESP_LOGW(TAG, "No calibration data found - using factory defaults. Consider running calibration.");
  }
  
  // CRITICAL: Enable crosstalk compensation (disabled by default per ST guide)
  // This is mandatory even without calibration data for proper operation
  ESP_LOGD(TAG, "Enabling crosstalk compensation (CRITICAL for accuracy)");
  VL53LX_Error status = VL53LX_SetXTalkCompensationEnable(this->device_, 1);
  if (status != VL53LX_ERROR_NONE) {
    ESP_LOGW(TAG, "Failed to enable crosstalk compensation: %d (%s)", status, get_error_string(status));
    // Continue anyway but log warning
  }
  
  ESP_LOGCONFIG(TAG, "VL53L3CX setup complete");
}

void VL53L3CXComponent::update() {
  if (!this->device_initialized_) {
    return;
  }
  
  // Check if measurement is ready
  uint8_t data_ready = 0;
  VL53LX_Error status = VL53LX_GetMeasurementDataReady(this->device_, &data_ready);
  
  if (status != VL53LX_ERROR_NONE) {
    ESP_LOGW(TAG, "Failed to check data ready: %d (%s)", status, get_error_string(status));
    return;
  }
  
  if (data_ready) {
    // Update binary sensor
    if (this->binary_sensor_ != nullptr) {
      this->binary_sensor_->publish_state(true);
    }
    
    this->read_measurement_();
    
    // Clear binary sensor after reading
    if (this->binary_sensor_ != nullptr) {
      this->binary_sensor_->publish_state(false);
    }
  }
}
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

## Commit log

2025-07-26 Initial commit: EasyEDA project files
    [BOM_VisionGuard.csv]
2025-08-09 upload rev.2 and firmware
    [BOM_VisionGuard.csv, BOM_VisionGuard_Rev_1.csv, BOM_VisionGuard_Rev_2.csv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]
